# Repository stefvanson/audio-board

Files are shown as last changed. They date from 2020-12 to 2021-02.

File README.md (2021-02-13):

# AudioBoard

This project contains the design files for an audio interface board (PCB).

## How to generate the files for JLCPCB

### Generate the gerber files and drill file

- File -> Plot: Select for Front and Bottom (F. and B.) the layers Cu, Mask, Paste and SilkS. Also select the Edge.Cuts layer.
  In that same window at bottom left click "Generate Drill Files..." and generate it.

### Generate the BOM

1. In the schematics editor (Eeschema) click the generate BOM button.
2. Select bom2group_csv and click "Generate".
3. JLCPCB expects the following columns, so adapt the generate CSV file to have these columns (rename and reorder columns):
	- Comment (the "Value" column)
	- Designator (the "Reference" column)
	- Footprint
	- LCSC (the "JLCPCB Part Number" column)

### Generate the pick and place file

1. In the PCB editor click File -> Fabrication Outputs -> Footprint Position (.pos) File.
2. Set the options to generate separate CSV files for the top and bottom and click "Generate Position File".
3. Now open the file and adapt the following column names:
    - Change "Ref" to "Designator"
	- Change "Rot" to "Rotation"
	- Change "Side" to "Layer"
	- Change "PosX" to "Mid X"
	- Change "PosY" to "Mid Y"
4. **Important!** Make sure to check the orientation of all components for which it matters carefully when ordering in JLCPCB!

### Making changes

If you make changes to the schematics you have to:

- Generate the netlist again (AudioBoard.net).
- Generate the BOM again (output/AudioBoard-BOM.csv).
- Load the netlist in the PCB editor and update the PCB with it. Make the required changes.
- Generate the gerber and drill files.
- Check the pick and place file (output/AudioBoard-top-PickAndPlace.csv)

## Known issues / To do list

- [x] MIDI connectors are rotated 180 degrees.
- [x] Fix MIDI Out pin routing (swap pin 4 and 5).
- [x] Fix MIDI Out resistors for 3.3V and change 5V to 3.3V
- [x] Make it more compact.
- [x] Change the footprint of the power connector.
- [x] Test UART
- [x] Connect VDD of Crystal
- [x] Fix I2S_DIN and I2S_DOUT pins (they are connected to the wrong teensy pins).
- [x] Use capacitors with lower voltage ratings
- [x] Add another MIDI output (3.5mm jack)
- [x] Add holes for mounting the PCB in a housing.
- [x] Add holes/pin header for connecting to raspberry Pi
- [x] Align outputs
- [x] Add labels for pin headers.
- [x] Update PCB version number
- [ ] The mounting holes for the Pi Innovo are ground and 3V3 on different sides
      so metal spacers conduct and create a short!

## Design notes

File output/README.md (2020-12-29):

Even though these files are mostly generated, some of them still require some
manual adaptations to match the format required by JLCPCB.

Also, these gerber files are updated whenever a new revision is going to be
ordered so we can always find back exactly what was used for ordering.

Therefore these files are also committed.

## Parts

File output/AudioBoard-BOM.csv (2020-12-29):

Comment | Designator | Footprint | LCSC
10uF6.3V | C12 C20 C18 C11 C13 C4 C3 | SamacSys_Parts:CAPC1005X70N | C15525
10nF50V | C16 C15 | SamacSys_Parts:CAPC2012X65N | C1710
2.2uF50V | C19 C23 | SamacSys_Parts:CAPC3216X180N | C50254
22uF25V | C2 C1 | SamacSys_Parts:CAPC2012X140N | C45783
100nF16V | C22 C21 C10 C17 C14 C9 C7 C8 | SamacSys_Parts:CAPC1005X55N | C1525
2.2nF50V | C28 C29 | SamacSys_Parts:CAPC2012X135N | C28260
1uF25V | C5 C6 C27 C25 C30 C26 C24 | SamacSys_Parts:CAPC1005X60N | C52923
SM4007PL | D1 | SamacSys_Parts:SODFL3718X125N | C64898
AMS1117-5.0 | IC1 | SamacSys_Parts:SOT229P700X180-4N | C6187
PCM5102APWR | IC2 | SamacSys_Parts:SOP65P640X120-20N | C107671
PCM1803ADBR | IC3 | SamacSys_Parts:SOP65P780X200-20N | C32076
I2S2_OPT | J1 | Connector_PinSocket_2.54mm:PinSocket_1x06_P2.54mm_Vertical
Raspberry_Pi_2_3 | J12 | Connector_PinHeader_2.54mm:PinHeader_2x20_P2.54mm_Vertical
57PC5F | J13 J14 | SamacSys_Parts:57PC5F
RCA_2x2 | J15 | SamacSys_Parts:PJRAS2X2S01X
SJ1-3523N | J16 | SamacSys_Parts:SJ13523N
Conn_01x06 | J17 | Connector_PinHeader_2.54mm:PinHeader_1x06_P2.54mm_Vertical
SPI_OPT | J2 | Connector_PinSocket_2.54mm:PinSocket_1x06_P2.54mm_Vertical
Other Teensy pins | J3 | Connector_PinSocket_2.54mm:PinSocket_1x04_P2.54mm_Vertical
UART_OPT | J4 | Connector_PinSocket_2.54mm:PinSocket_1x03_P2.54mm_Vertical
163-179PH-EX | J5 | SamacSys_Parts:BarrelJack_Horizontal
EXTRA_POWER | J6 | Connector_PinSocket_2.54mm:PinSocket_1x03_P2.54mm_Vertical
POT | J7 J8 J9 J10 J11 | Connector_PinSocket_2.54mm:PinSocket_1x03_P2.54mm_Vertical
Teensy supply select | JP1 | Connector_PinSocket_2.54mm:PinSocket_1x03_P2.54mm_Vertical
MODE0 | JP2 | Connector_PinSocket_2.54mm:PinSocket_1x02_P2.54mm_Vertical
MODE1 | JP3 | Connector_PinSocket_2.54mm:PinSocket_1x02_P2.54mm_Vertical
BYPAS | JP4 | Connector_PinSocket_2.54mm:PinSocket_1x02_P2.54mm_Vertical
OSC_DIS | JP5 | Connector_PinSocket_2.54mm:PinSocket_1x02_P2.54mm_Vertical
33 | R10 R6 | SamacSys_Parts:R_0805_JLCPCB | C17634
10 | R11 R16 | SamacSys_Parts:R_1206_JLCPCB | C17903
100 | R12 R13 | SamacSys_Parts:R_0805_JLCPCB | C17408
470 | R14 R15 R1 R2 R3 R4 R5 | SamacSys_Parts:R_0805_JLCPCB | C17710
220 | R7 R9 | SamacSys_Parts:R_0402_JLCPCB | C25091
10k | R8 R17 | SamacSys_Parts:R_0402_JLCPCB | C25744
TestPoint | TP1 | Connector_PinHeader_2.54mm:PinHeader_1x01_P2.54mm_Vertical
Teensy4.0 | U1 | teensy:Teensy40
6N138SDM | U2 | Package_DIP:SMDIP-8_W9.53mm | C188666
24.576MHz | U3 | Crystal:Crystal_SMD_3225-4Pin_3.2x2.5mm | C27869

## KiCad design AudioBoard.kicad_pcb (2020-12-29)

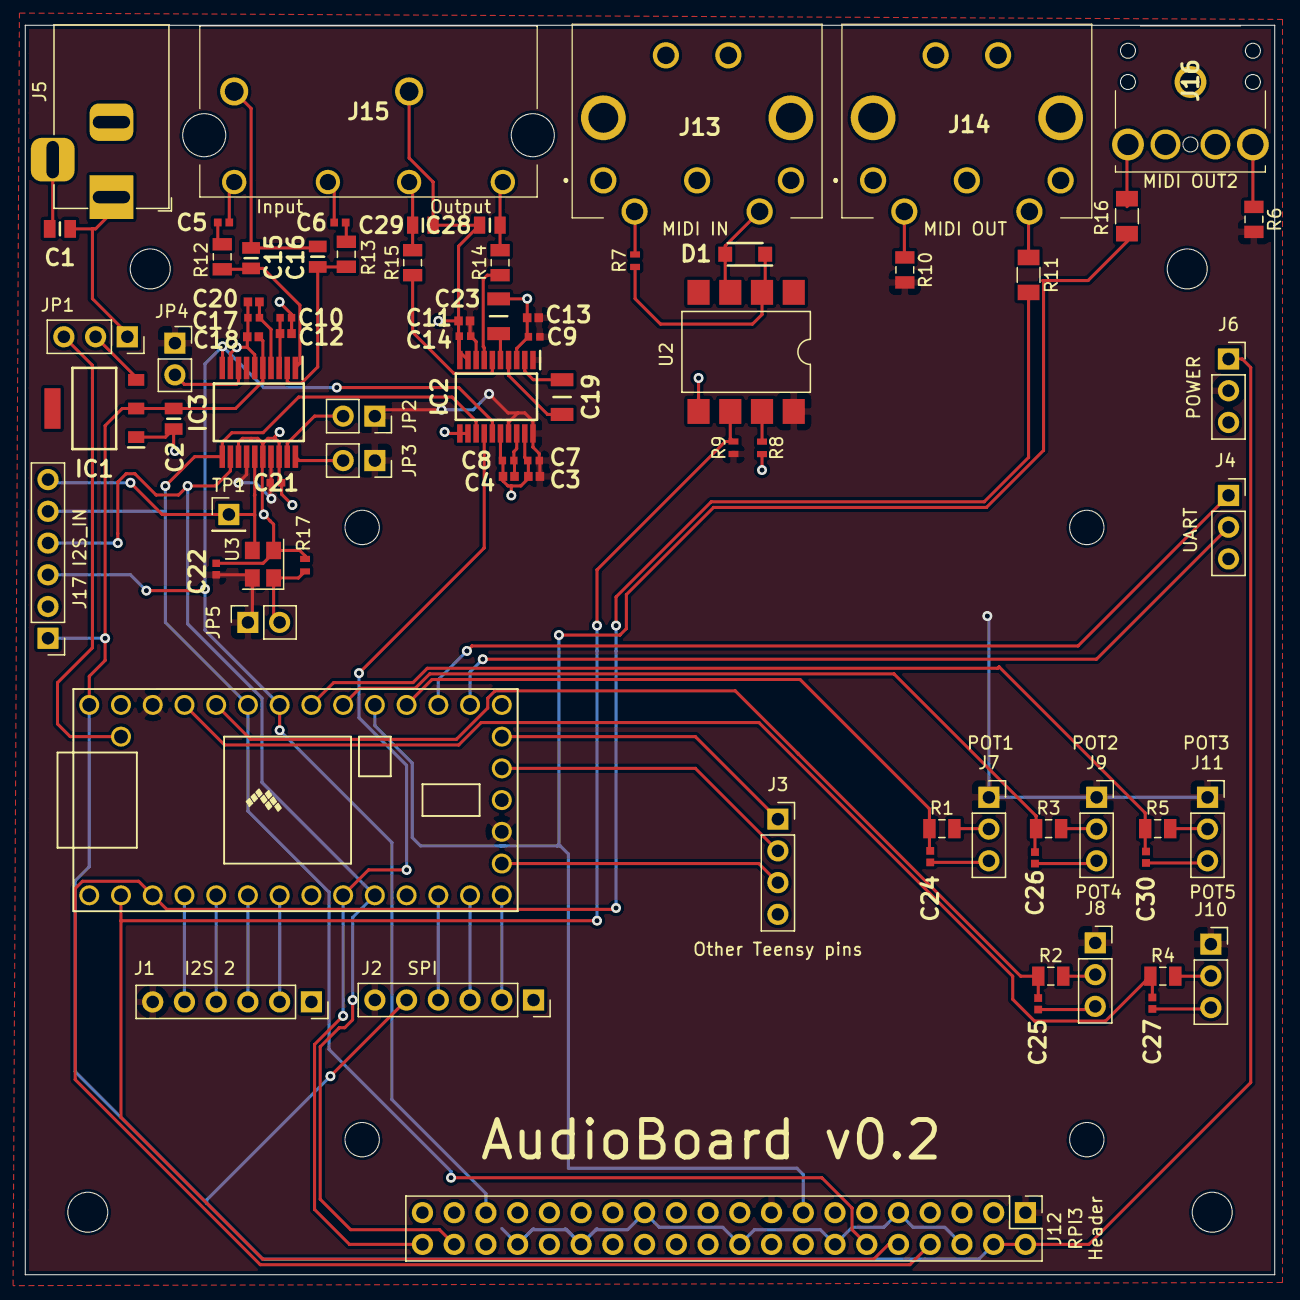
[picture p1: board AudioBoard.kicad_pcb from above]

Board: 2 copper layers, 100.0 x 100.0 mm, 77 parts (0 on the bottom side), 64 nets.

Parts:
C1, C2: 22uF25V; CAPC2012X140N
C3, C4, C11, C12, C13, C18, C20: 10uF6.3V; CAPC1005X70N
C5, C6, C24, C25, C26, C27, C30: 1uF25V; CAPC1005X60N
C7, C8, C9, C10, C14, C17, C21, C22: 100nF16V; CAPC1005X55N
C15, C16: 10nF50V; CAPC2012X65N
C19, C23: 2.2uF50V; CAPC3216X180N
C28, C29: 2.2nF50V; CAPC2012X135N
D1: SM4007PL; SODFL3718X125N
IC1: AMS1117-5.0; SOT229P700X180-4N
IC2: PCM5102APWR; SOP65P640X120-20N
IC3: PCM1803ADBR; SOP65P780X200-20N
J1: I2S2_OPT; PinSocket_1x06_P2.54mm_Vertical
J2: SPI_OPT; PinSocket_1x06_P2.54mm_Vertical
J3: Other Teensy pins; PinSocket_1x04_P2.54mm_Vertical
J4: UART_OPT; PinSocket_1x03_P2.54mm_Vertical
J5: 163-179PH-EX; BarrelJack_Horizontal
J6: EXTRA_POWER; PinSocket_1x03_P2.54mm_Vertical
J7, J8, J9, J10, J11: POT; PinSocket_1x03_P2.54mm_Vertical
J12: Raspberry_Pi_2_3; PinHeader_2x20_P2.54mm_Vertical
J13, J14: 57PC5F
J15: RCA_2x2; PJRAS2X2S01X
J16: SJ1-3523N; SJ13523N
J17 I2S_IN: Conn_01x06; PinHeader_1x06_P2.54mm_Vertical
JP1: Teensy supply select; PinSocket_1x03_P2.54mm_Vertical
JP2: MODE0; PinSocket_1x02_P2.54mm_Vertical
JP3: MODE1; PinSocket_1x02_P2.54mm_Vertical
JP4: BYPAS; PinSocket_1x02_P2.54mm_Vertical
JP5: OSC_DIS; PinSocket_1x02_P2.54mm_Vertical
R1, R2, R3, R4, R5, R14, R15: 470; R_0805_JLCPCB
R6, R10: 33; R_0805_JLCPCB
R7, R9: 220; R_0402_JLCPCB
R8, R17: 10k; R_0402_JLCPCB
R11, R16: 10; R_1206_JLCPCB
R12, R13: 100; R_0805_JLCPCB
TP1: TestPoint; PinHeader_1x01_P2.54mm_Vertical
U1: Teensy4.0; Teensy40
U2: 6N138SDM; SMDIP-8_W9.53mm
U3: 24.576MHz; Crystal_SMD_3225-4Pin_3.2x2.5mm

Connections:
+3V3: C3.2, C7.1, C9.1, C11.2, C13.2, C14.1, C21.1, C22.1, IC2.1, IC2.8, IC2.17, IC2.20, IC3.7, IC3.14, IC3.17, J1.6, J2.6, J6.2, J7.1, J8.1, J9.1, J10.1, J11.1, J12.1, J12.17, JP2.1, JP3.1, JP4.1, JP5.1, R6.2, R9.1, R10.2, U1.16, U1.31, U2.8, U3.4
+5V: C2.1, C18.2, IC1.2, IC3.5, J2.5, J6.1, J12.2, J12.4, J17 I2S_IN.1, U1.33
/Audio IO (I2S)/IN_L: C15.1, IC3.1, R12.2
/Audio IO (I2S)/IN_R: C16.2, IC3.2, R13.2
/Audio IO (I2S)/JP_BYPAS: IC3.8, JP4.2
/Audio IO (I2S)/JP_MODE0: IC3.19, JP2.2
/Audio IO (I2S)/JP_MODE1: IC3.20, JP3.2
/Audio IO (I2S)/OUT_L: IC2.6, R15.1
/Audio IO (I2S)/OUT_R: IC2.7, R14.1
/Audio IO (I2S)/RCA_IN_L: C5.1, J15.4
/Audio IO (I2S)/RCA_IN_R: C6.1, J15.3
/Audio IO (I2S)/RCA_OUT_L: C29.1, J15.2, R15.2
/Audio IO (I2S)/RCA_OUT_R: C28.1, J15.1, R14.2
/Audio IO (I2S)/SCK: IC3.15, J17 I2S_IN.6, TP1.1, U3.3
/DC_IN: C1.1, J5.A, JP1.1
/I2S2_BCK: J1.3, U1.6
/I2S2_DIN: J1.2, U1.7
/I2S2_DOUT: J1.5, U1.4
/I2S2_LRCK: J1.4, U1.5
/I2S_BCK: IC2.13, IC3.11, J12.12, J17 I2S_IN.5, U1.28
/I2S_DIN: IC3.12, J12.38, J17 I2S_IN.4, U1.10
/I2S_DOUT: IC2.14, J12.40, U1.9
/I2S_LRCK: IC2.15, IC3.10, J12.35, J17 I2S_IN.3, U1.27
/MIDI_IN: J12.10, R9.2, U1.2, U2.6
/MIDI_OUT: J12.8, R11.2, U1.3
/MIDI_OUT2: J12.15, R16.2, U1.24
/POT1: C24.1, R1.1, U1.23
/POT2: C26.1, R3.1, U1.25
/POT3: C30.1, R5.1, U1.26
/POT4: C25.1, R2.1, U1.29
/POT5: C27.1, R4.1, U1.30
/UART_OPT_RX: J4.1, U1.22
/UART_OPT_TX: J4.2, U1.21
/V_USB: JP1.3, U1.34
GND: C1.2, C2.2, C3.1, C4.2, C7.2, C8.1, C9.2, C10.2, C11.1, C12.1, C13.1, C14.2, C15.2, C16.1, C17.2, C18.1, C20.1, C21.2, C22.2, C23.1, C24.2, C25.2, C26.2, C27.2, C28.2, C29.2, C30.2, IC1.1, IC2.3, IC2.9, IC2.10, IC2.11, IC2.12, IC2.16, IC2.19, IC3.6, IC3.9, IC3.13, IC3.16, IC3.18, J1.1, J2.1, J3.4, J4.3, J5.B, J5.C, J6.3, J7.3, J8.3, J9.3, J10.3, J11.3, J12.6, J12.9, J12.14, J12.20, J12.25, J12.30, J12.34, J12.39, J13.6, J13.7, J14.2, J14.6, J14.7, J15.5, J15.6, J16.1, J17 I2S_IN.2, R8.2, R17.2, U1.1, U1.17, U1.32, U2.5, U3.2
unnamed: C4.1, C8.2, IC2.18
unnamed: C5.2, R12.1
unnamed: C6.2, R13.1
unnamed: C10.1, C12.2, IC3.3
unnamed: C17.1, C20.2, IC3.4
unnamed: C19.1, IC2.2
unnamed: C19.2, IC2.4
unnamed: C23.2, IC2.5
unnamed: D1.1, R7.2, U2.2
unnamed: D1.2, J13.5, U2.3
unnamed: IC1.3, JP1.2
unnamed: J2.2, U1.14
unnamed: J2.3, U1.13
unnamed: J2.4, U1.12
unnamed: J3.1, U1.19
unnamed: J3.2, U1.18
unnamed: J3.3, U1.15
unnamed: J7.2, R1.2
unnamed: J8.2, R2.2
unnamed: J9.2, R3.2
unnamed: J10.2, R4.2
unnamed: J11.2, R5.2
unnamed: J13.4, R7.1
unnamed: J14.4, R10.1
unnamed: J14.5, R11.1
unnamed: J16.2, R16.1
unnamed: J16.3, R6.1
unnamed: JP5.2, R17.1, U3.1
unnamed: R8.1, U2.7

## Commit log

2020-09-05 Initial version that was ordered AudioBoard v0.1
    [AudioBoard-B_Cu.gbr, AudioBoard-B_Mask.gbr, AudioBoard-B_Paste.gbr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]
2020-09-05 Cleaned up project.
    [AudioBoard-BOM.csv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]
2020-12-27 Updated MIDI schematic and orientation and to do list. Note: Gerber not updated.
    [AudioBoard.kicad_pcb, MIDI.sch]
2020-12-27 Fixed I2S pins (connected the right ones)
    [AudioBoard.sch]
2020-12-27 Updated barreljack (power) footprint and added V_USB selection through jumper.
    [AudioBoard.sch]
2020-12-27 Updated I2S crystal/oscillator
    [AudioIO.sch]
2020-12-27 Updated capacitors to smaller/lower voltage ones.
    [AudioBoard.sch, AudioIO.sch, Placeholders for IO.sch]
2020-12-27 Replaced one pot by a 3.5mm MIDI Output jack.
    [AudioBoard.sch, MIDI.sch, Placeholders for IO.sch]
2020-12-28 Aligned outputs, started on tracing and connected Pi Innovo header in schematic.
    [AudioBoard.kicad_pcb, AudioBoard.sch, AudioIO.sch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]
2020-12-29 Updated PCB traces.
    [AudioBoard.kicad_pcb, AudioBoard.sch]
2020-12-29 Added mounting holes and wrapped up PCB design.
    [AudioBoard-BOM.csv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]
2020-12-29 Added pin header for I2S input, to connect an external ADC (the PCM1803ADBR was unavailable at the time of ordering).
    [AudioBoard-BOM.csv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]
2021-02-13 Added to do for spacer bug (short due to GND and 3V3 on opposite sides)
